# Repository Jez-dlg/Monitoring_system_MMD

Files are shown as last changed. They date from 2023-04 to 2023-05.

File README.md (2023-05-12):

# Monitoring_system_MMD
<Div Align=Justify>
Projet académique EI2I4 HF système de monitoring <br>
<dt>Ce projet permet de surveiller l'environnement intérieur en mesurant la température, l'humidité, la pression atmosphérique, le niveau de CO2 et le niveau sonore d'une salle de classe permettant d'alerter un gestionnaire si les taux deviennent trop élevés. </Div> <br>
  
<B> Matériel nécessaire : </B>
  
  - Arduino MKR1310 permettant une connexion LoraWan pour envoyer les données et les afficher en ligne sur Ubidots
  - Le capteur BME280 qui permet de récupérer la température, l'humidité et la pression atmosphérique
  - Le capteur de CO2 COZIR-LP-5000
  - Le capteur sonore SEN0487
  - Un écran E-Ink 2,9"
  - Deux panneaux solaires d'intérieur
  - Une batterie de 1000 mA
  - PCB
  - Modèle 3D

<B> Installation : </B>

<Div Align=Justify>Installez l'IDE Arduino sur votre ordinateur si ce n'est pas déjà fait. <br>
Créez un compte sur The Things Network (https://www.thethingsnetwork.org/) et Ubidots (https://ubidots.com/) <br>
Branchez les capteurs et l'écran E-Ink sur les broches correspondantes de l'Arduino MKR1310 en suivant le schéma suivant : </Div>

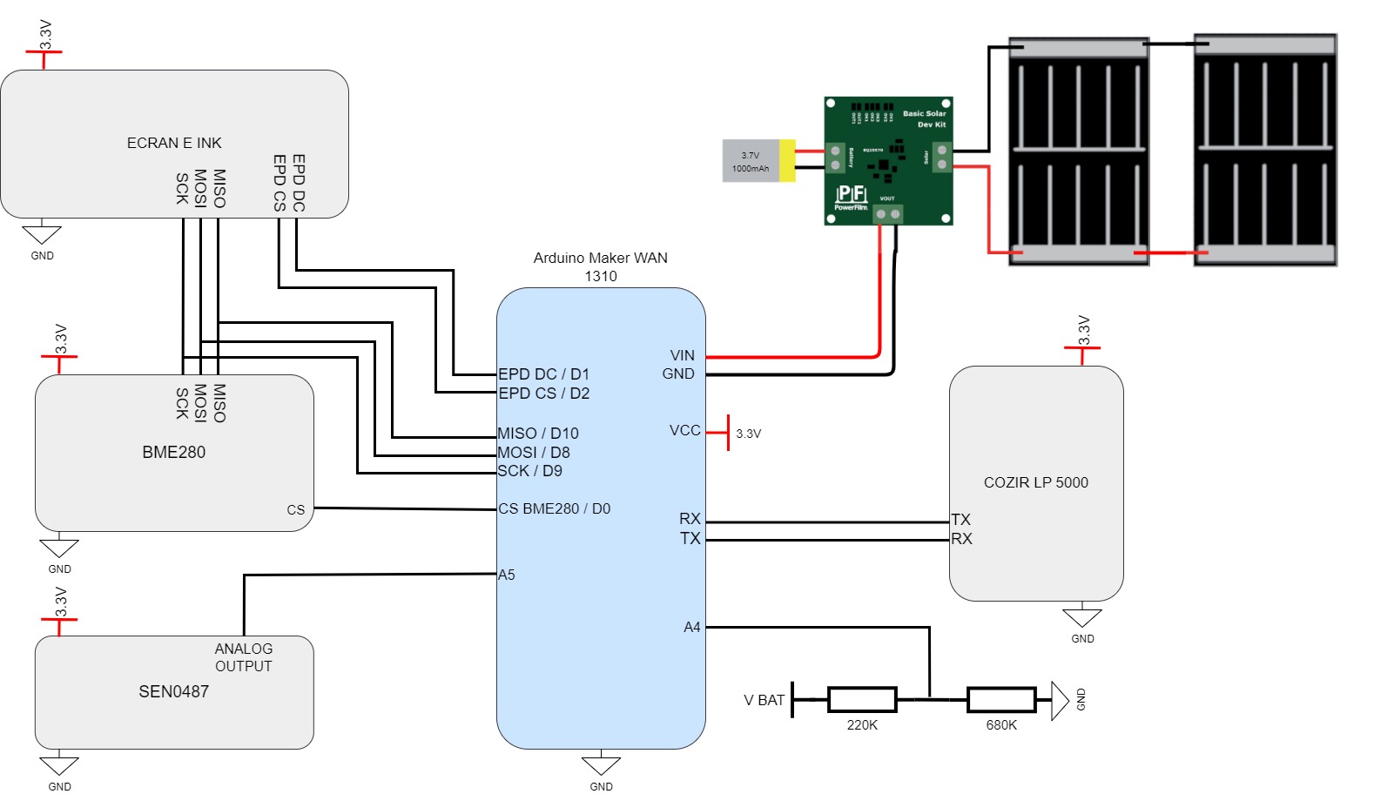
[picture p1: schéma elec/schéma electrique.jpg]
github-small


  <B>Téléchargez et installez les bibliothèques nécessaires sur Aduino IDE :</B>
  
- Wire.h
- SPI.h
- Adafruit_Sensor.h
- Adafruit_BME280.h
- Arduino.h
- cozir.h
- Adafruit_ThinkInk.h
- avr/dtostrf.h
- MKRWAN.h
- ArduinoLowPower.h

Ouvrez le fichier code_pj2.ino dans l'IDE Arduino. <br>
Compilez et téléversez le code sur votre Arduino MKR1310.

  <B>Utilisation :</B>

<Div Align=Justify>Le système mesure les données d'une salle de classe toutes les 10 minutes et affiche les valeurs sur l'écran E-Ink. Si le niveau de CO2 dépasse le seuil défini (1200 ppm) pendant 10 minutes, des alertes sont aussi paramétrés pour la température et le niveau sonore. <br> Les données sont envoyées via LoRaWAN à un serveur distant pour être analysées. <br>
Les données peuvent être visualisées sur un dashboard Ubidots ou sur l'écran directement. </Div>

<br>
  <B>Optimisation de la consommation d'énergie :</B><br>
  
  Pour maximiser la durée de vie de la batterie et minimiser la consommation d'énergie, le système utilise les techniques suivantes :
  - Attente plus courte le jour pour réduire le temps de prise de mesure
  - Mise en veille du capteur de CO2 lorsqu'il n'est pas utilisé
  - Utilisation d'un écran E-Ink pour minimiser la consommation d'énergie
  - Utilisation d'un panneau solaire pour recharger la batterie

  <B>Contribution :</B>

Si vous souhaitez contribuer à ce projet, n'hésitez pas à envoyer des pull requests ou des issues sur GitHub.

  <B>Auteurs :</B>

Malo N (neuville.malo@gmail.com)<br>
Mael O-S (saugerm@gmail.com)<br>
Dylan LG (dylan.leguilloux@gmail.com)

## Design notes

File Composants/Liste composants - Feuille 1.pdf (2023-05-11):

Dénomination | Référence constructeur | Code commande | Quantité | Fournisseur | Lien URL | Montant TTC
capteur CO2 | cozir-LP-5000 | | 1 | Digi-Key | lien (https://www.digikey.fr/fr/products/detail/gas-sensing-solutions-ltd/COZIR-LP-5000/9952877?productid=9952877) | 59,72
kit dev panneau solaire indoor | DEV-BASIC Powerfilm | | 1 | Mouser | lien (https://www.mouser.fr/ProductDetail/PowerFilm/DEV-BASIC?qs=BJlw7L4Cy7%2Fw4dHFXPm5kg%3D%3D) | 55,97
capteur humidité,pression,T° | adafruit 2652 | | 1 | Digi-Key | lien (https://www.digikey.fr/fr/products/detail/adafruit-industries-llc/2652/5604372?productid=5604372) | 16,4
ecran e ink adafruit | adafruit 4777 | | 1 | Digi-Key | lien (https://www.digikey.fr/en/products/detail/adafruit-industries-llc/4777/13536256) | 24,68
capteur niveau audio | SEN0487 | | 1 | GoTronic | | 4,9
batterie rechargeable RS PRO 3.7V Lithium-Ion 7.8Ah 144-9408 | | | 1 | RS Components | lien (https://fr.rs-online.com/web/p/blocs-batteries-rechargeables/1449408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) | 36,8
ARDUINO_MKR_WAN_1310 | | | 1
mosfet p sot 23 | BSS83P | | 1
Regulateur de tension 3,3V | MIC5504-3.3YM5-TR | | 1

Module de chargement 4056 USB-C

resistance 1K 0805 | | | 1
resistance 100K 0805 | | | 1
resistance 220K 0805 | | | 1
resistance 680K 0805 | | | 1
condensateur 1uf 0805 | | | 2
connecteur 1,27mm femelle 6pin | | | 1
Commutateur à bascule, On-Aucun-On 1MD1T1B1M1QE | | | 1 | | lien (https://fr.farnell.com/multicomp/1md1t1b1m1qe/interrupteur-dpdt/dp/9473513)
Bouton-poussoir miniature, Momentané, Unipolaire à une direction, 400 mA @ 32 V c.a., Noir, Montage panneau RS7346704 | | | 1
Interrupteur à bascule KCD11-101 3A/250V | | | 1 | | lien (https://fr.aliexpress.com/item/33014133239.html)

pins 2,54 male

pins 2,54 femelle

insert M3 | | | 14
VIS M3*6 | | | 8
VIS M3*6 fraisé | | | 6
Aimant neodyme 6*3 | | | 6

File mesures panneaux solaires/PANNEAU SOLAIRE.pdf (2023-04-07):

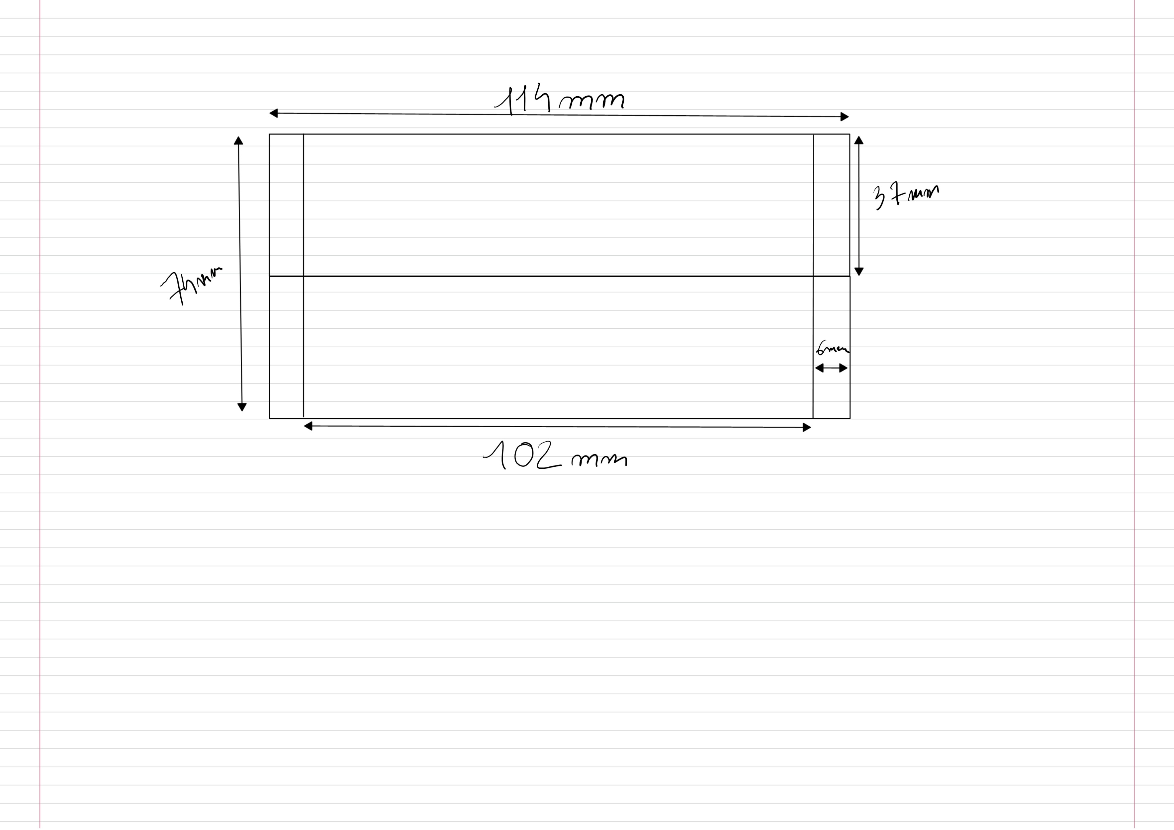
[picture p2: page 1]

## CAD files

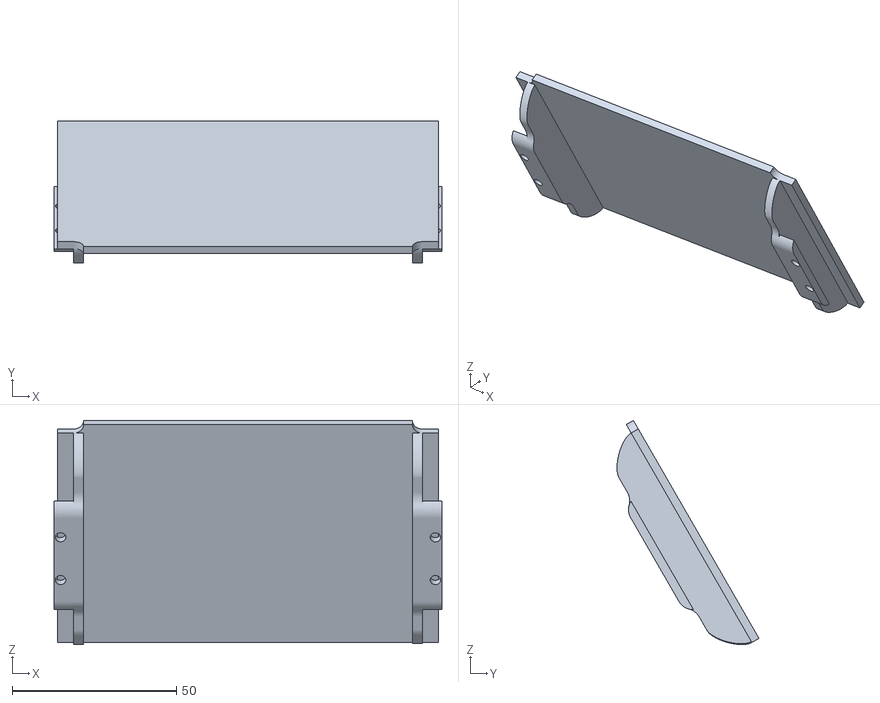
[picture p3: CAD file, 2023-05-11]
3D/support panneau.stl
118.0 x 43.2 x 68.2

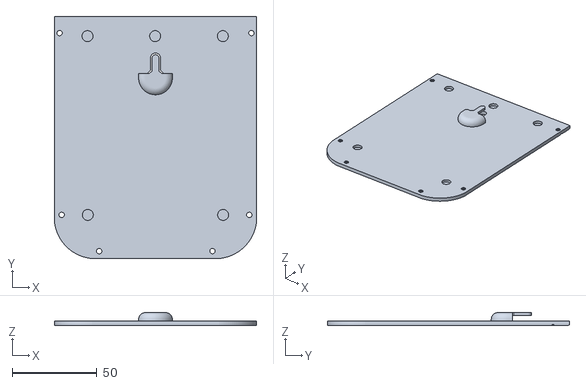
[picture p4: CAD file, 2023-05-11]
3D/facearrière.stl
119.6 x 143.1 x 7.60

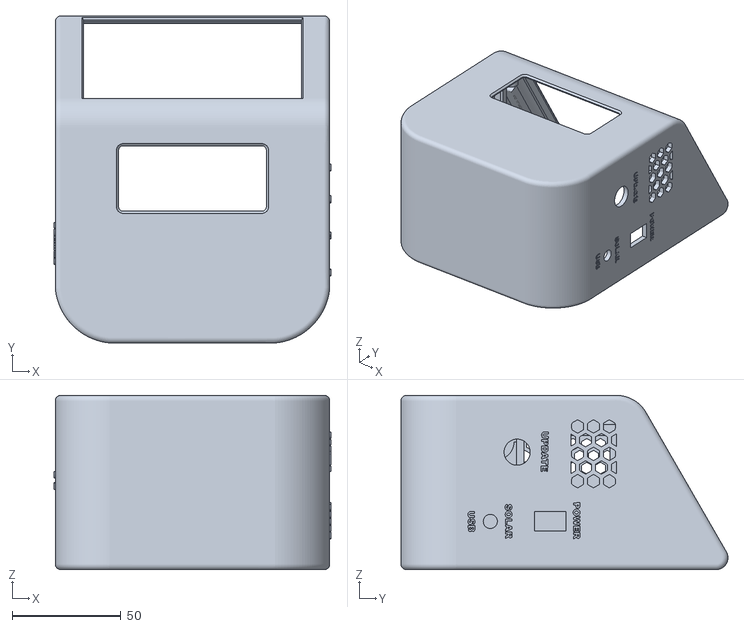
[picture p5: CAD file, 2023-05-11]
3D/boitier.stl
127.0 x 150.1 x 80.0

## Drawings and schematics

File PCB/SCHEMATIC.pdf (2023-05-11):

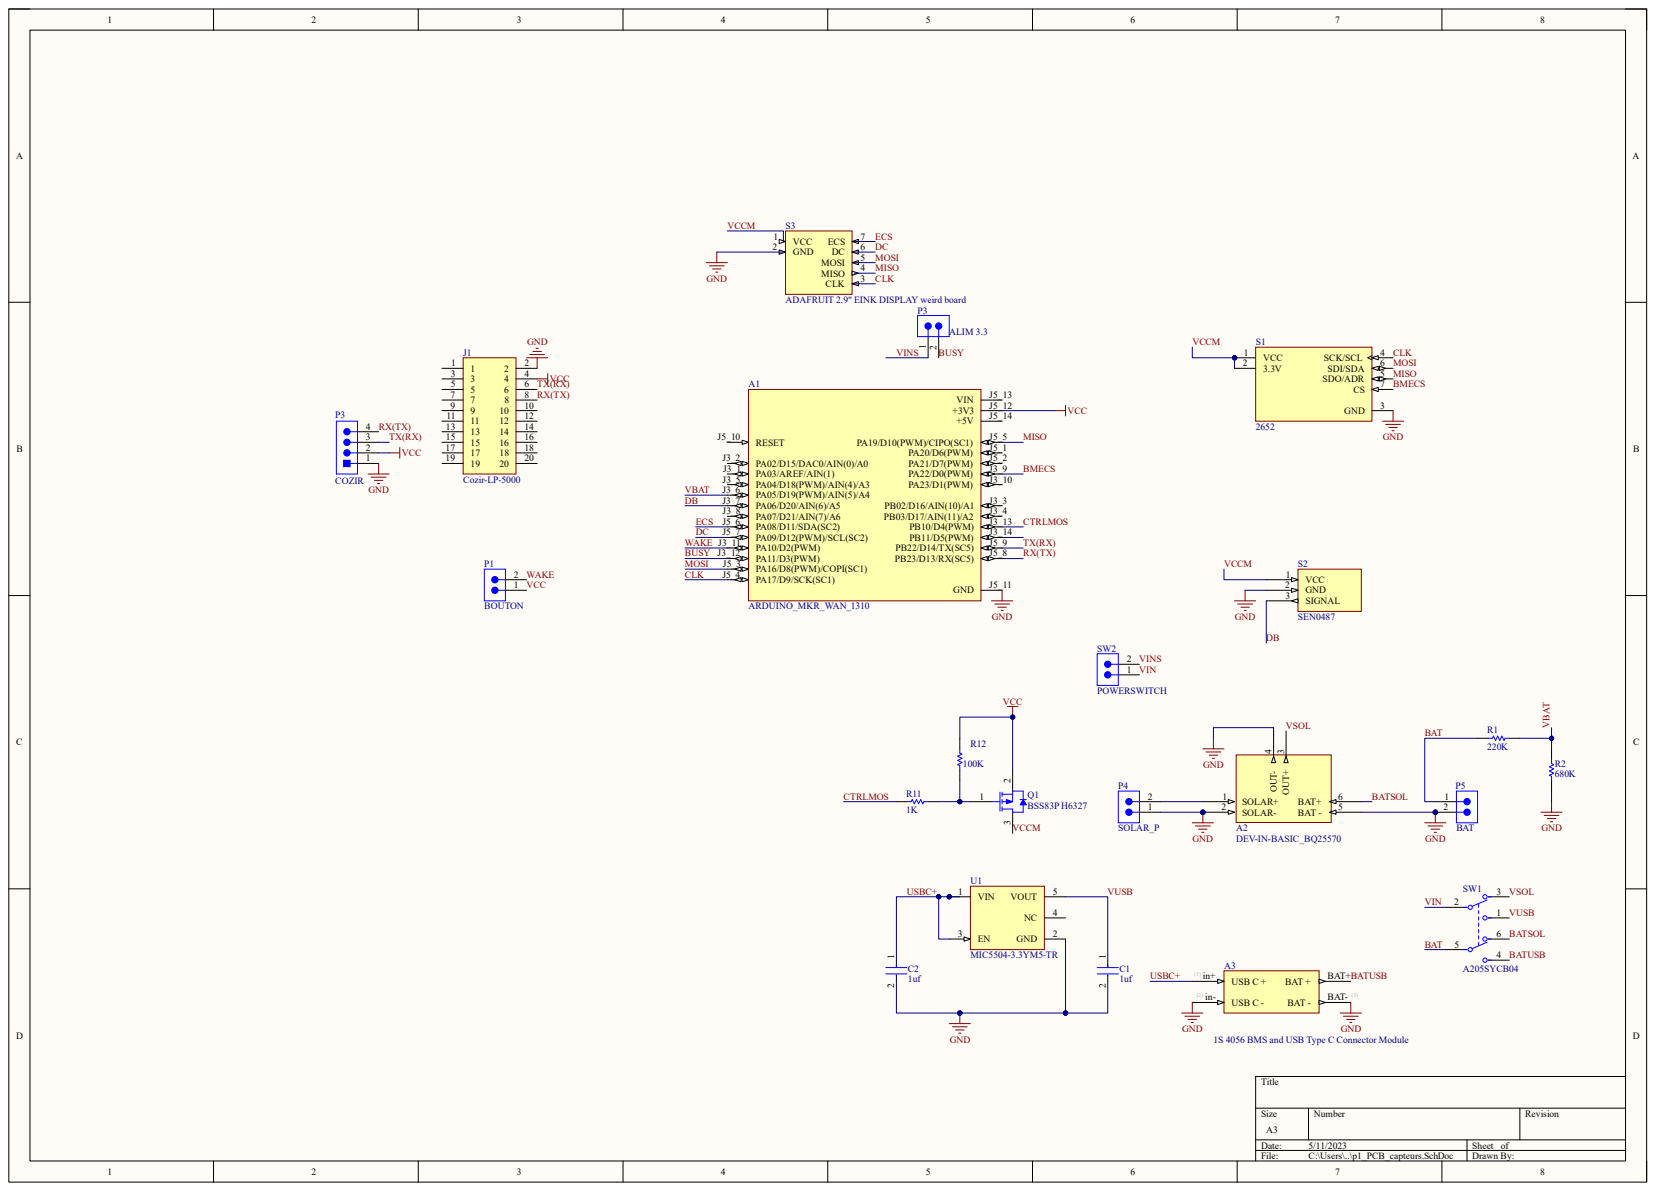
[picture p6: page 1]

ADAFRUIT 2.9" EINK DISPLAY weird board

1S 4056 BMS and USB Type C Connector Module ¹ ²
USBC+

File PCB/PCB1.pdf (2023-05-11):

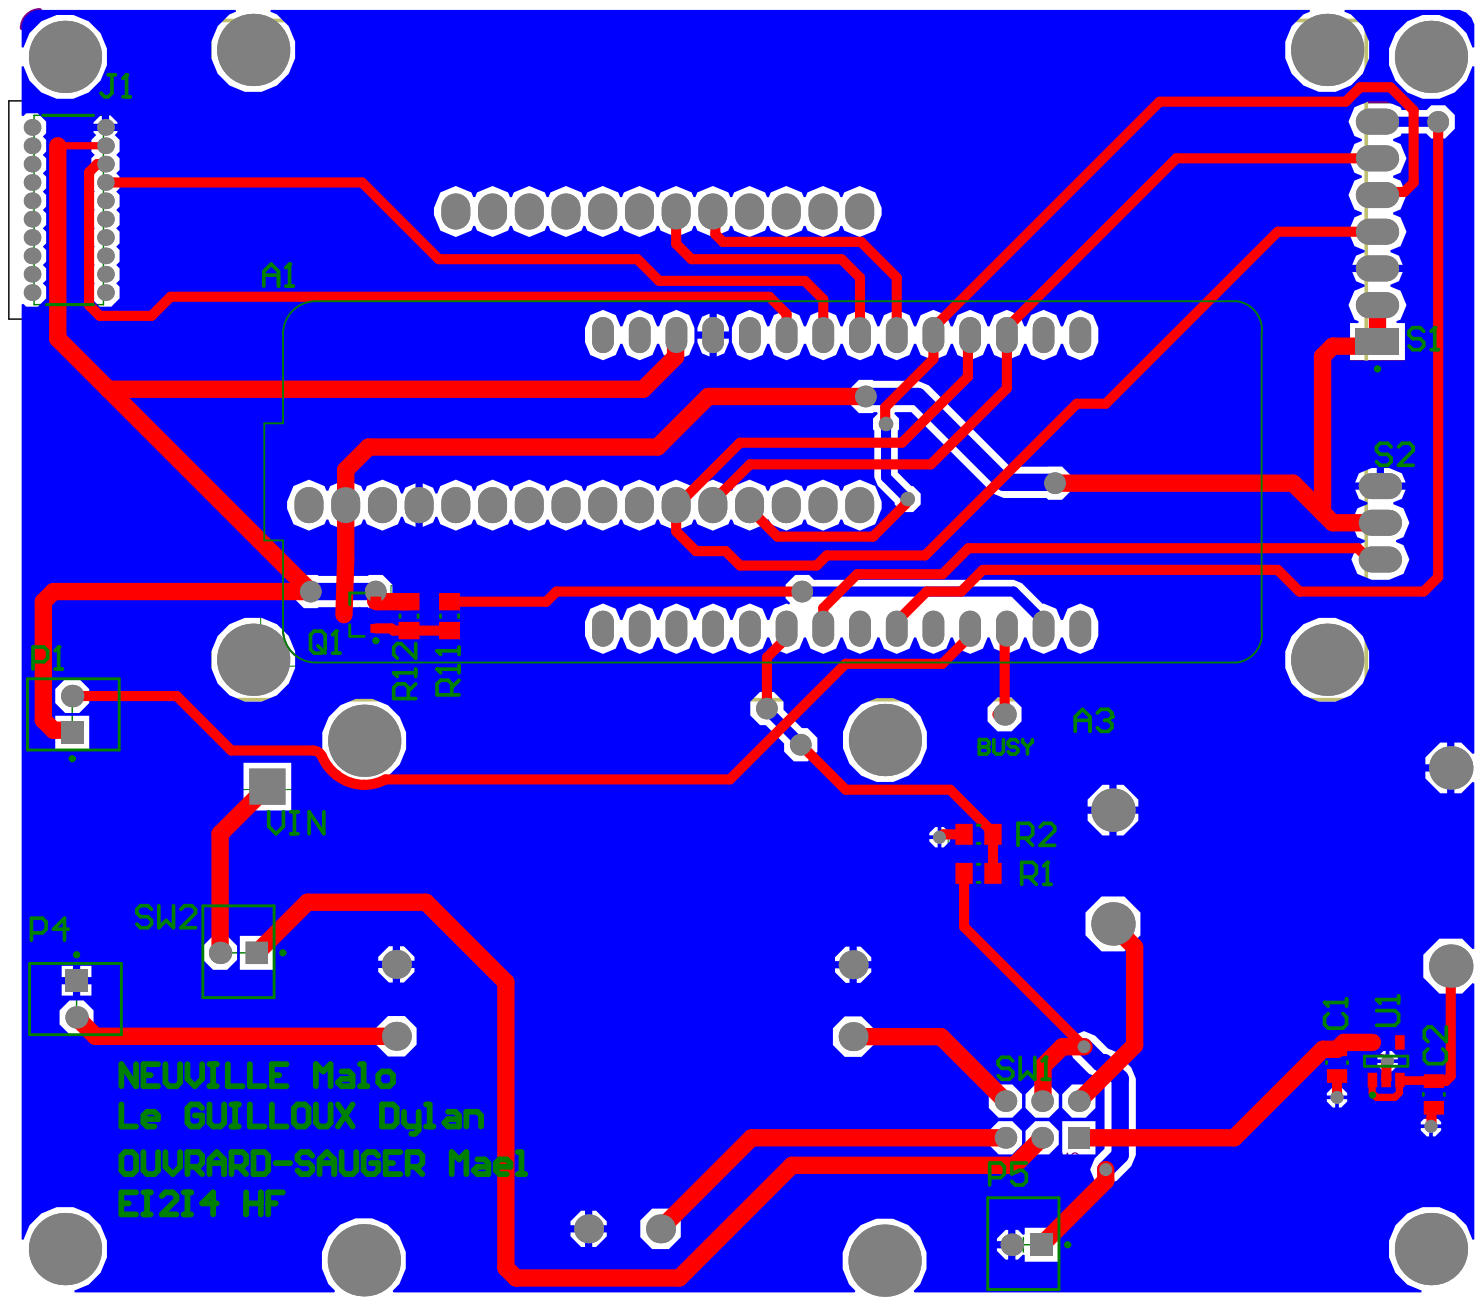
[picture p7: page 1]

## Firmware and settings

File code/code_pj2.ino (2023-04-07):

#include <MKRWAN.h>
#include "DHT.h"

#define DHTPIN 2  
#define DHTTYPE DHT11
LoRaModem modem;
String appEui = "0000000000000000";
String appKey = "D4379CF960659806F75CB42B6312B0BE";
bool connected;
short con;
DHT dht(DHTPIN, DHTTYPE);

int soundPin = A1; // Broche de signal du capteur de bruit
int sampleWindow = 50; // Fenêtre d'échantillonnage en millisecondes
unsigned int sample;


void setup() {
 Serial.begin(115200);
 while (!Serial);
 //Serial.println("Welcome to MKR WAN 1300/1310 ");
 modem.begin(EU868);
 //Serial.println(F("DHTxx test!"));
 dht.begin();
 connected=false;
 if ( !connected ) {
 //Serial.print("Join test : ");
 //Serial.println(++con);
 int ret=modem.joinOTAA(appEui, appKey);
 if ( ret ) {
 connected=true;
 modem.minPollInterval(60);
 //Serial.println("Connected");
 modem.dataRate(5); // switch to SF7
 delay(100); // because ... more stable
 }
 }
 delay(1000); // apparently the murata dislike if this tempo is removed...
 con =0;

}
void loop() {
  if ( !connected ) {
 //Serial.print("Join test : ");
 //Serial.println(++con);
 int ret=modem.joinOTAA(appEui, appKey);
 if ( ret ) {
 connected=true;
 modem.minPollInterval(60);
 //Serial.println("Connected");
 modem.dataRate(5); // switch to SF7
 delay(100); // because ... more stable
 }
 }

 if ( connected ) {

  // Lecture capteur
  float t = dht.readTemperature();
  float h = dht.readHumidity();
  
  unsigned long startMillis = millis(); // Début de la fenêtre d'échantillonnage
  unsigned int peakToPeak = 0; // Amplitude de crête à crête du signal

  unsigned int signalMax = 0;
  unsigned int signalMin = 1024;

  // Échantillonnage du signal
  while (millis() - startMillis < sampleWindow) {
    sample = analogRead(soundPin);
    if (sample < 1024) {
      if (sample > signalMax) {
        signalMax = sample; // Mise à jour de la valeur maximale
      } else if (sample < signalMin) {
        signalMin = sample; // Mise à jour de la valeur minimale
      }
    }
  }
  peakToPeak = signalMax - signalMin; // Calcul de l'amplitude de crête à crête

  // Conversion en dB
  float value = (peakToPeak * 10.0) / 1024.0; // Conversion de la tension du signal en volts
  float dB = 20 * log10(value/0.001); // Conversion de la tension en dB

  // Conversion en short
  int16_t t_short = (int16_t)(t * 100);
  int16_t h_short = (int16_t)(h * 100);
  int16_t dB_short = (int16_t)(dB * 100);

  // Envoi LoRaWAN
  modem.beginPacket();
  modem.write((uint8_t*)&t_short, sizeof(t_short));
  modem.write((uint8_t*)&h_short, sizeof(h_short));
  modem.write((uint8_t*)&dB_short, sizeof(dB_short));
  modem.endPacket();

 /* // Affichage console
  Serial.print("Température : ");
  Serial.print(t, 2); // Affiche deux décimales
  Serial.print(" °C, Humidité : ");
  Serial.print(h, 2); // Affiche deux décimales
  Serial.print(" %");
  Serial.print(" Bruit : ");
  Serial.print(dB, 2); // Affiche deux décimales
  Serial.println(" dB");*/

  // Check if any reads failed and exit early (to try again).
  if (isnan(h) || isnan(t)) {
    Serial.println(F("Failed to read from DHT sensor!"));
    return;
  }
  delay(30000);
 }
 
 }
